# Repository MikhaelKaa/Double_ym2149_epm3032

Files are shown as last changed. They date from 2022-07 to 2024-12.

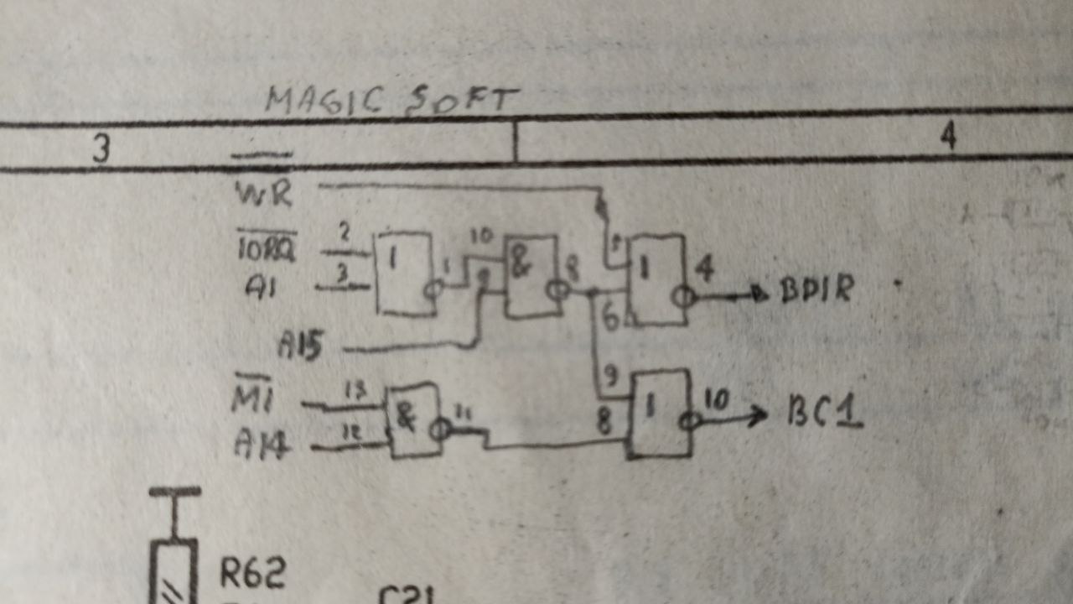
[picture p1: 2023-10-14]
docs/info/2.jpg

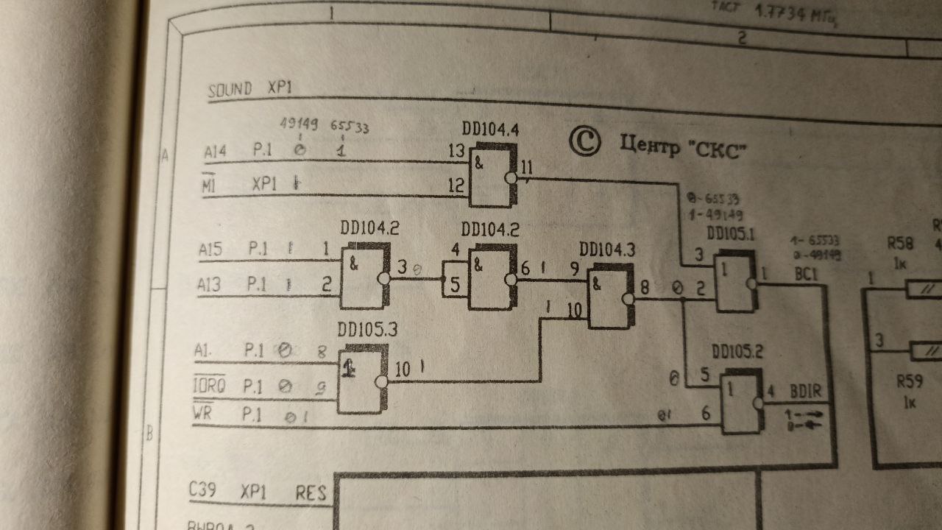
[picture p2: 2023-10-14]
docs/info/1.jpg

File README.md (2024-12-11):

# TurboSound #

### --- ###

* Две YM2149
* Логика выборки в epm3032
* Covox на КР572ПА1А

## Вариант реализации в виде печатной платы:

Автор трассировки.
https://github.com/ponchick/TS_Ext_EPM3032

### Версия прошивки для платы 1.5 без каких либо доработок:
/docs/1.5fix/EPM3032_ponchick_ver1.5.pof


### Версия прошивки для 1.5 с доработками:
/docs/1.5fix/EPM3032_ponchick_ver1.5fix.pof


## Макет с ковоксом:




В планах: добавить цифровую регулировку громкости.

Идеи и предложения принимаются.

## Благодарности:

Михаил Андреев ака Микка - за тесты карточки.

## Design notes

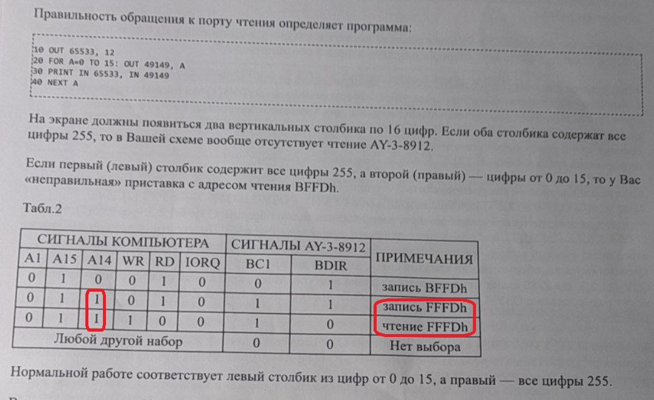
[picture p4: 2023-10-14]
docs/info/table_ym.jpg

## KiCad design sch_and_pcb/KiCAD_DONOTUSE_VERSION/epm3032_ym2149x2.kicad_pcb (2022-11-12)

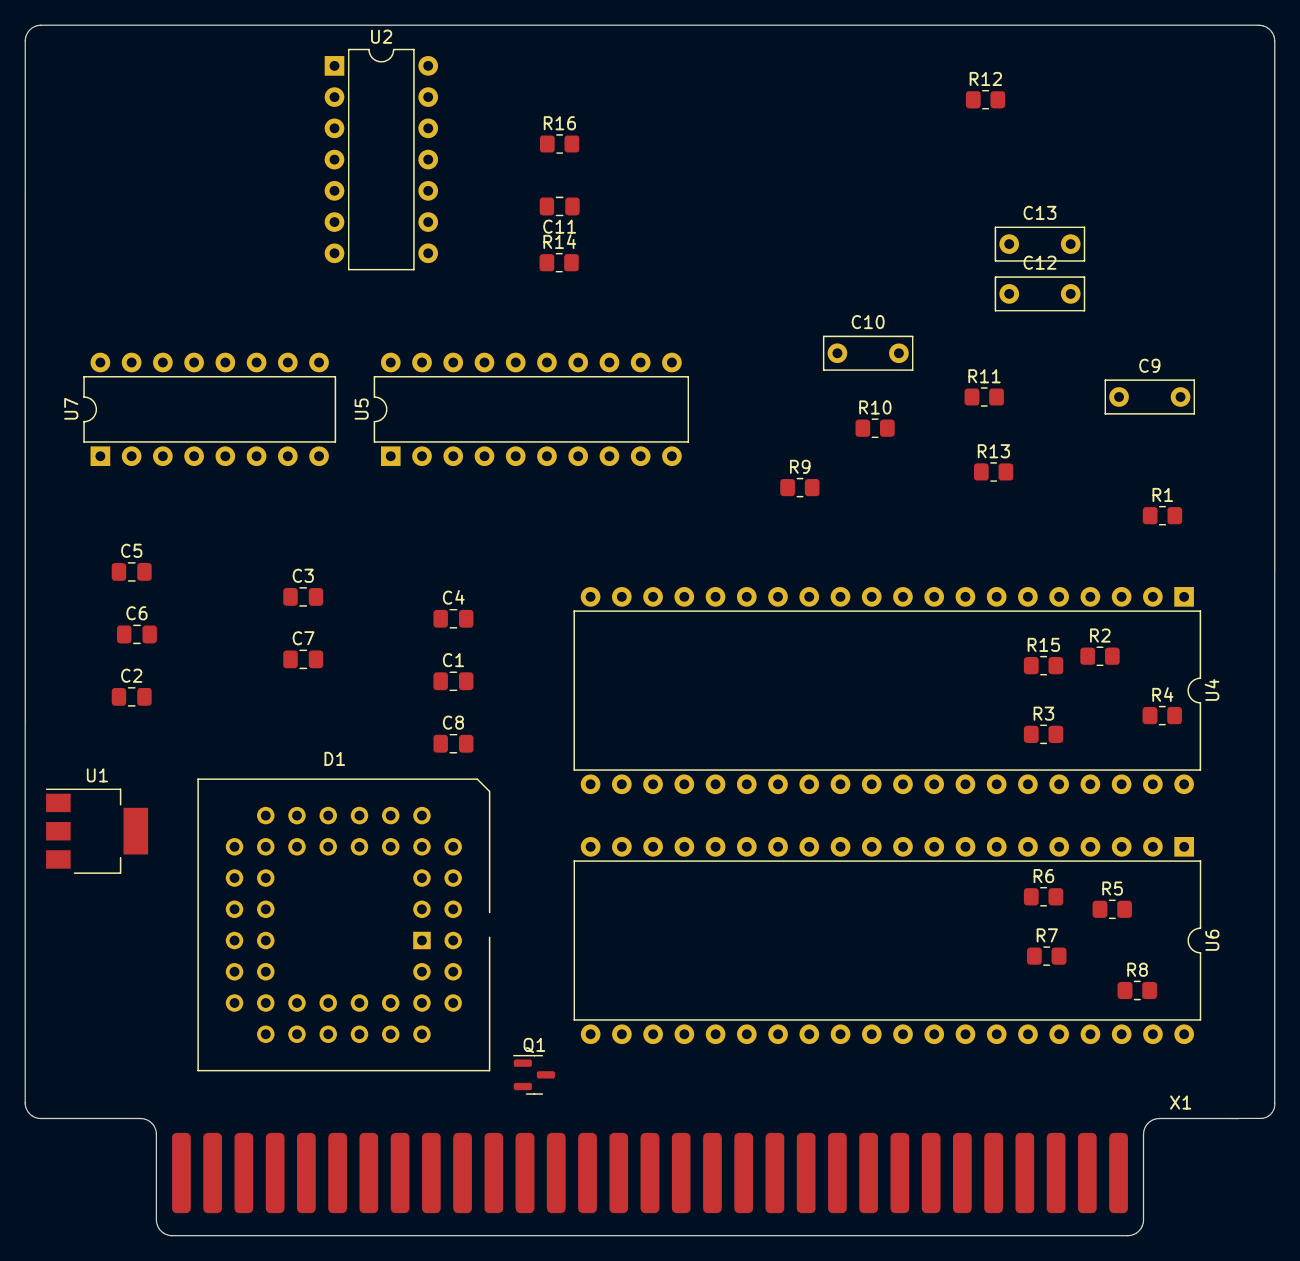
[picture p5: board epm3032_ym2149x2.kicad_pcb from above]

Board: 2 copper layers, 101.6 x 98.4 mm, 38 parts (0 on the bottom side), 50 nets, no tracks yet.

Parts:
C1: 10uF10VX7R0805; C_0805_2012Metric_Pad1.18x1.45mm_HandSolder
C2, C3, C4, C5, C6, C7, C8, C11: 0.47uF50VX7R0805; C_0805_2012Metric_Pad1.18x1.45mm_HandSolder
C9, C10, C12, C13: 0.47uF wima; C_Rect_L7.0mm_W2.5mm_P5.00mm
D1: epm3032; PLCC-44_THT-Socket
Q1: BC847; SOT-23
R1, R4, R5, R8: 4.7K; R_0805_2012Metric_Pad1.20x1.40mm_HandSolder
R2, R3, R6, R7, R11, R12, R13, R14, R15, R16: 10K; R_0805_2012Metric_Pad1.20x1.40mm_HandSolder
R9, R10: 1K; R_0805_2012Metric_Pad1.20x1.40mm_HandSolder
U1: AMS1117-3.3; SOT-223-3_TabPin2
U2: LM324; DIP-14_W7.62mm
U4, U6: YM2149; DIP-40_W15.24mm
U5: 74HC374; DIP-20_W7.62mm
U7: AD7533JN; DIP-16_W7.62mm
X1: zx-bus

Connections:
/+3.3V: C2.1, C4.1, C6.1, C7.1, U1.2 (VO)
/+5V: C1.1, C3.1, C5.1, C8.1, Q1.3 (C), R16.1, U1.3 (VI), U2.4 (V+), U4.28 (BC2), U4.40 (VCC), U6.28 (BC2), U6.40 (VCC)
/GND: C1.2, C2.2, C3.2, C4.2, C5.2, C6.2, C7.2, C8.2, C11.2, D1.10 (gnd), R9.1, R10.1, R14.1, U1.1 (GND), U2.11 (V-), U4.1 (VSS), U4.24 (~A9), U6.1 (VSS), U6.24 (~A9), X1.29 (GND), X1.37 (GND), X1.38 (GND), X1.45 (GND), X1.61 (GND)
/IOGE: Q1.2 (E), X1.44 (IOGE)
/YM_0_A: R1.1, U4.3 (A)
/YM_0_B: R2.1, R3.1, U4.4 (B)
/YM_0_C: R4.1, U4.38 (C)
/YM_1_A: R5.1, U6.3 (A)
/YM_1_B: R6.1, R7.1, U6.4 (B)
/YM_1_C: R8.1, U6.38 (C)
/a0: D1.11 (io), X1.40 (A0)
/a1: D1.9 (io), X1.41 (A1)
/a8_0: D1.19 (io), U4.25 (A8)
/a8_1: D1.20 (io), U6.25 (A8)
/a14: D1.29 (io), X1.2 (A13)
/a15: D1.31 (io), X1.1 (A15)
/bc1: D1.16 (io), U4.29 (BC1), U6.29 (BC1)
/bdir: D1.14 (io), U4.27 (BDIR), U6.27 (BDIR)
/clk175: D1.18 (io), U4.22 (CLOCK), U6.22 (CLOCK)
/clk350: D1.43 (clk), X1.39 (3.5)
/d0: D1.34 (io), U4.37 (DA0), U6.37 (DA0), X1.6 (D0)
/d1: D1.28 (io), U4.36 (DA1), U6.36 (DA1), X1.7 (D1)
/d2: U4.35 (DA2), U6.35 (DA2), X1.8 (D2)
/d3: D1.41 (io), U4.34 (DA3), U6.34 (DA3), X1.11 (D3)
/d4: D1.5 (io), U4.33 (DA4), U6.33 (DA4), X1.12 (D4)
/d5: D1.40 (io), U4.32 (DA5), U6.32 (DA5), X1.10 (D5)
/d6: D1.39 (io), U4.31 (DA6), U6.31 (DA6), X1.9 (D6)
/d7: D1.33 (io), U4.30 (DA7), U6.30 (DA7), X1.3 (D7)
/ioge_c: D1.27 (io), Q1.1 (B)
/iorq: D1.6 (io), X1.17 (IORQ)
/m1: D1.8 (io), X1.23 (M1)
/reset: D1.4 (io), U4.23 (~RESET), U6.23 (~RESET), X1.51 (RES)
/wr: D1.12 (io), X1.18 (RD)
unnamed: C9.1, R1.2, R2.2, R5.2, R6.2, R9.2
unnamed: C9.2, R11.1
unnamed: C10.1, R12.1
unnamed: C10.2, R3.2, R4.2, R7.2, R8.2, R10.2
unnamed: C11.1, R14.2, R16.2, U2.10 (+), U2.12 (+)
unnamed: C12.1, R13.2, U2.8
unnamed: C13.2, R15.2, U2.14
unnamed: R11.2, R13.1, U2.9 (-)
unnamed: R12.2, R15.1, U2.13 (-)
unnamed: U5.2 (O0), U7.4 (D9(MSB))
unnamed: U5.5 (O1), U7.5 (D8)
unnamed: U5.6 (O2), U7.6 (D7)
unnamed: U5.9 (O3), U7.7 (D6)
unnamed: U5.12 (O4), U7.8 (D5)
unnamed: U5.15 (O5), U7.9 (D4)
unnamed: U5.16 (O6), U7.10 (D3)
unnamed: U5.19 (O7), U7.11 (D2)

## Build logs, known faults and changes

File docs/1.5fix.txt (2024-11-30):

Доработки для платы версии 1.5 за авторством ponchick (ttps://github.com/ponchick/TS_Ext_EPM3032)
Доработки связанные с тактированием Ямах.
1. Разрезать дорожку от ламели по которой идет клок из шины (на схеме обозначена как b8)
2. Ламель b8 соеденить с U1-43
3. Вывод U1-18 соеденить с U3-22
4. В любом удобном месте разместить переключатель, один полюс которого соеденен с землей, другой через резистор 1к с 3.3В, 
 средную точку подключить к U1-1. Переключая можно выбрать делитель частоты тактирования ямах (без деления, деление на два - для работы в режиме турбо)
Доработки связанные с дешифрацией (совместимость с портом dffd и просто корректная работа).
1. Ламель b11 (сигнал А2) соеденить с U1-44
2. Ламель b12 (сигнал А3) соеденить с U1-26
3. Ламель а18 (сигнал RD) соеденить с U1-37
3. Ламель а2 (сигнал А13) соеденить с U1-28

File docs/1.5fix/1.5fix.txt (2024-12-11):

Доработки для платы версии 1.5 за авторством ponchick (ttps://github.com/ponchick/TS_Ext_EPM3032)
Доработки связанные с тактированием Ямах.
1. Разрезать дорожку от ламели по которой идет клок из шины (на схеме обозначена как b8)
2. Ламель b8 (сигнал clk) соеденить с U1-43 
3. Вывод U1-18 соеденить с U3-22
4. В любом удобном месте разместить переключатель, один полюс которого соеденен с землей,
 другой через резистор 1к с 3.3В, средную точку подключить к U1-1. 
 Переключая можно выбрать делитель частоты тактирования ямах (без деления, деление на два - для работы в режиме турбо)
 При подаче 3.3В на U1-1 клок с шины идет на ямахи без деления.
 При соеденении U1-1 с GND частота клока делится на два.
5. Ламель а13 (сигнал INT) соеденить с U1-2 (Этот сигнал нужен для автоматического выбора делителя клока, может быть не поддержано в прошивке)

Доработки связанные с дешифрацией (совместимость с портом dffd и просто корректная работа).
1. Ламель b11 (сигнал А2) соеденить с U1-44
2. Ламель b12 (сигнал А3) соеденить с U1-26
3. Ламель а18 (сигнал RD) соеденить с U1-37
4. Ламель а2 (сигнал А13) соеденить с U1-28

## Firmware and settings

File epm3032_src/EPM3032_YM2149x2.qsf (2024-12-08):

# -------------------------------------------------------------------------- #
#
# Copyright (C) 1991-2013 Altera Corporation
# Your use of Altera Corporation's design tools, logic functions 
# and other software and tools, and its AMPP partner logic 
# functions, and any output files from any of the foregoing 
# (including device programming or simulation files), and any 
# associated documentation or information are expressly subject 
# to the terms and conditions of the Altera Program License 
# Subscription Agreement, Altera MegaCore Function License 
# Agreement, or other applicable license agreement, including, 
# without limitation, that your use is for the sole purpose of 
# programming logic devices manufactured by Altera and sold by 
# Altera or its authorized distributors.  Please refer to the 
# applicable agreement for further details.
#
# -------------------------------------------------------------------------- #
#
# Quartus II 64-Bit
# Version 13.0.1 Build 232 06/12/2013 Service Pack 1 SJ Web Edition
# Date created = 20:15:30  May 20, 2022
#
# -------------------------------------------------------------------------- #
#
# Notes:
#
# 1) The default values for assignments are stored in the file:
#		EPM3032_YM2149x2_assignment_defaults.qdf
#    If this file doesn't exist, see file:
#		assignment_defaults.qdf
#
# 2) Altera recommends that you do not modify this file. This
#    file is updated automatically by the Quartus II software
#    and any changes you make may be lost or overwritten.
#
# -------------------------------------------------------------------------- #


set_global_assignment -name FAMILY MAX3000A
set_global_assignment -name DEVICE "EPM3032ALC44-10"
set_global_assignment -name TOP_LEVEL_ENTITY EPM3032_YM2149x2
set_global_assignment -name ORIGINAL_QUARTUS_VERSION "13.0 SP1"
set_global_assignment -name PROJECT_CREATION_TIME_DATE "20:15:30  MAY 20, 2022"
set_global_assignment -name LAST_QUARTUS_VERSION "13.0 SP1"
set_global_assignment -name PROJECT_OUTPUT_DIRECTORY output_files
set_global_assignment -name ERROR_CHECK_FREQUENCY_DIVISOR "-1"
set_global_assignment -name VERILOG_FILE EPM3032_YM2149x2.v
set_global_assignment -name MAX7000_DEVICE_IO_STANDARD "3.3-V LVTTL"
set_location_assignment PIN_9 -to a1
set_location_assignment PIN_29 -to a14
set_location_assignment PIN_31 -to a15
set_location_assignment PIN_16 -to bc1
set_location_assignment PIN_14 -to bdir
set_location_assignment PIN_6 -to iorq
set_location_assignment PIN_8 -to m1
set_location_assignment PIN_12 -to wr
set_location_assignment PIN_11 -to a0
set_location_assignment PIN_21 -to beeper
set_location_assignment PIN_24 -to tapeout
set_location_assignment PIN_4 -to reset
set_location_assignment PIN_27 -to ioge_c
set_location_assignment PIN_44 -to a2
set_location_assignment PIN_25 -to covox
set_location_assignment PIN_34 -to d_0
set_location_assignment PIN_41 -to d_3
set_location_assignment PIN_5 -to d_4
set_location_assignment PIN_40 -to d_5
set_location_assignment PIN_39 -to d_6
set_location_assignment PIN_33 -to d_7
set_location_assignment PIN_43 -to cpu_clock
set_location_assignment PIN_18 -to ym_clock
set_location_assignment PIN_19 -to ym_0
set_location_assignment PIN_20 -to ym_1
set_location_assignment PIN_37 -to rd
set_location_assignment PIN_26 -to a3
set_location_assignment PIN_28 -to a13
set_global_assignment -name TIMEQUEST_MULTICORNER_ANALYSIS OFF
set_global_assignment -name SMART_RECOMPILE ON
set_global_assignment -name OPTIMIZE_HOLD_TIMING OFF
set_global_assignment -name OPTIMIZE_MULTI_CORNER_TIMING OFF
set_global_assignment -name FITTER_EFFORT "STANDARD FIT"
set_location_assignment PIN_1 -to div2
set_location_assignment PIN_2 -to interrupt

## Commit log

2022-07-05 >> пусть будет...
    [epm3032_ym2149x2.kicad_pcb, epm3032_ym2149x2.kicad_sch]
2022-07-06 >> продолжаем продолжать. Макетка рулез.
    [epm3032_ym2149x2.kicad_pcb, epm3032_ym2149x2.kicad_sch]
2022-08-10 >> прототип на макетке поет
    [epm3032_ym2149x2.kicad_pcb, epm3032_ym2149x2.kicad_sch]
2022-10-03 >> d7 33 to 26 pin
    [epm3032_ym2149x2.kicad_sch]
2022-11-09 >> auto detect and division cpu clock 3.5/7 MHz for YM.
    [epm3032_ym2149x2.kicad_sch]
2022-11-12 >> добавил сигнал dos, нужно тестировать.
    [epm3032_ym2149x2.kicad_pcb, epm3032_ym2149x2.kicad_sch]
2023-10-09 >> Эксперементы.
2023-10-11 >> Добавлены в gitignore файлы backups KiCad
2023-10-11 >> Добавлена заготовка под testbench.
2023-10-11 >> Эксперименты на тему определения турбо режима. Пока успехов нет.
2023-10-14 >> Все сломалось и не работает.
    [epm3032_ym2149x2.kicad_pcb, epm3032_ym2149x2.kicad_sch]
2023-10-14 >> Добавил в тест примеры. Вывод по условию и ожидание событий.
2024-04-17 >> Исправления в коде CPLD.
    [EPM3032_YM2149x2.qsf]
2024-04-18 >>Вариант дешифрации с rd
2024-05-01 >> После сброса активен первый чип.
2024-11-15 fix: README.md добавил репу с печатной платой.
2024-11-28 add: Первый запуск версии 1.5
2024-11-28 add: предупреждение о баге.
2024-11-29 todo: доделать tb.v
2024-11-30 add: Версия 1.5fix
2024-12-07 fix: Старая версия оставлена как исторический артефакт.
    [epm3032_ym2149x2.kicad_pcb, epm3032_ym2149x2.kicad_sch]
2024-12-07 fix: Версия прошивки. Железо 1.5fix. Нужно тестировать.
2024-12-07 fix: теперь iorqge чуть раньше iorq.
2024-12-08 add: Прошивка под 1.5fix для GMX. Добавлен сигнал int для детекта турбы.
2024-12-08 fix: Исправленная версия прошивки для 1.5fix.
2024-12-11 fix: Дополнил инструкции.
